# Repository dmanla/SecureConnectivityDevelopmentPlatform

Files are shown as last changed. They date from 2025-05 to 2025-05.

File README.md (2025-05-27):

# Arduino-Mega Compatible Secure Connectivity Development Platform

**WARNING**: This project is under development and has not yet been validated.

This is an open hardware platform designed for the development of secure wired-network applications. It is fully compatible with all Arduino Mega-compatible hardware and software.

This project was inspired by (but not a copy of) the Freetronics EtherMega: https://github.com/freetronics/EtherMega
This project was created as an alternative to the platform offered by Freetronics.

Features:
- CH340 USB->Serial Converter (Functionally similar to FT232, Driver should be installed automatically)
- Jumper Configurable IO: Certain pins (D3, D6, D8, D9, D13) can be connected to the headers or to integrated peripheral pins.
- 5V 2A USB-C Input
- 6V - 32V VIN Input 
- MicroSD Card Slot
- 10/100 Ethernet provided over SPI using the W6100. Supports Auto-Negotiations, IPv4, IPv6, and Auto-MIDX.
- SE050 EdgeLock Plug and Trust Secure Element to provide security features for connected applications, accessible using I2C
- ISM330DHCX Inertial Measurement Unit, accessible using I2C
- MCP7940N Real Time Clock, accessible using I2C
- Level Shifted I2C: Provides connection points for 3V3 I2C Devices (Extra Header), and 5V I2C Devices (Standard Mega Headers)

## Top Render
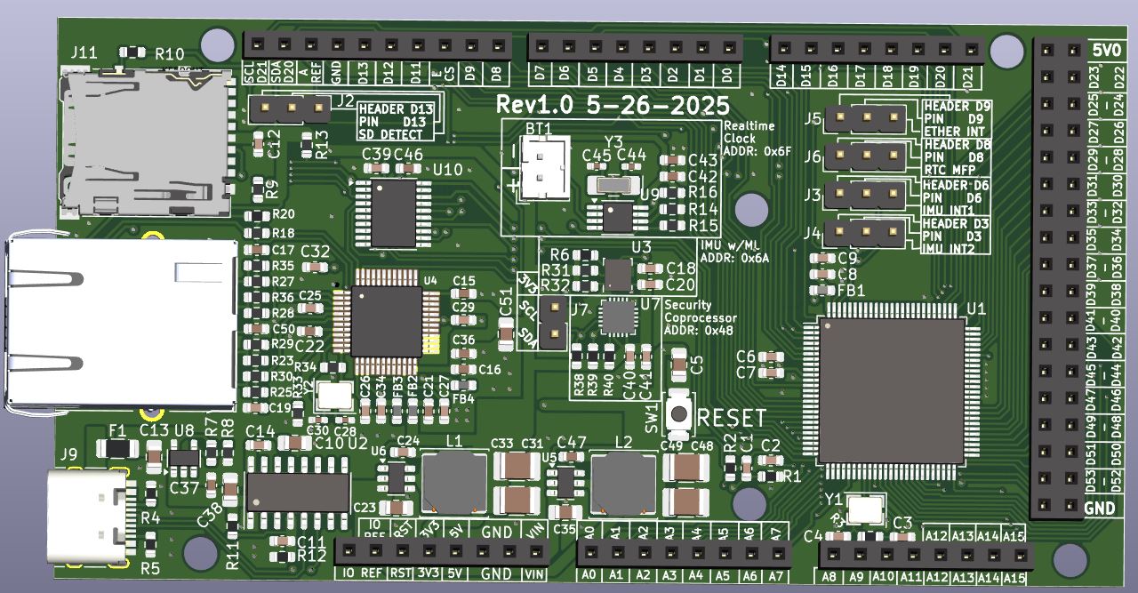
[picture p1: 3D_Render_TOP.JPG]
Render of Top of PCB


## Bottom Render
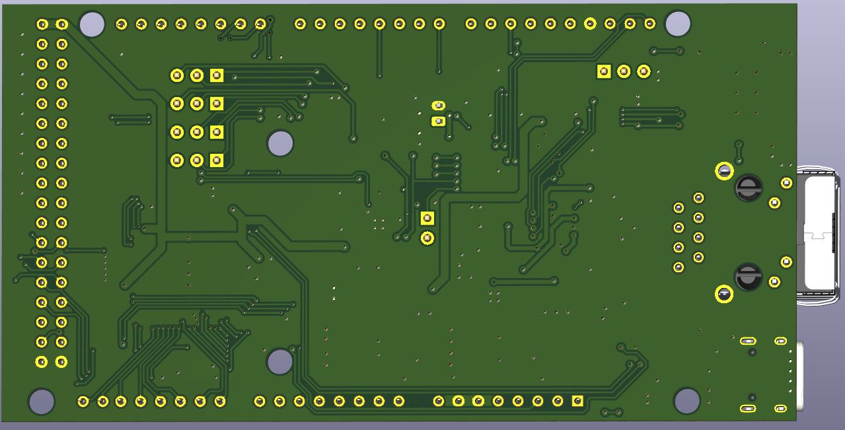
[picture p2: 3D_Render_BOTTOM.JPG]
Render of Bottom of PCB


## Side Render
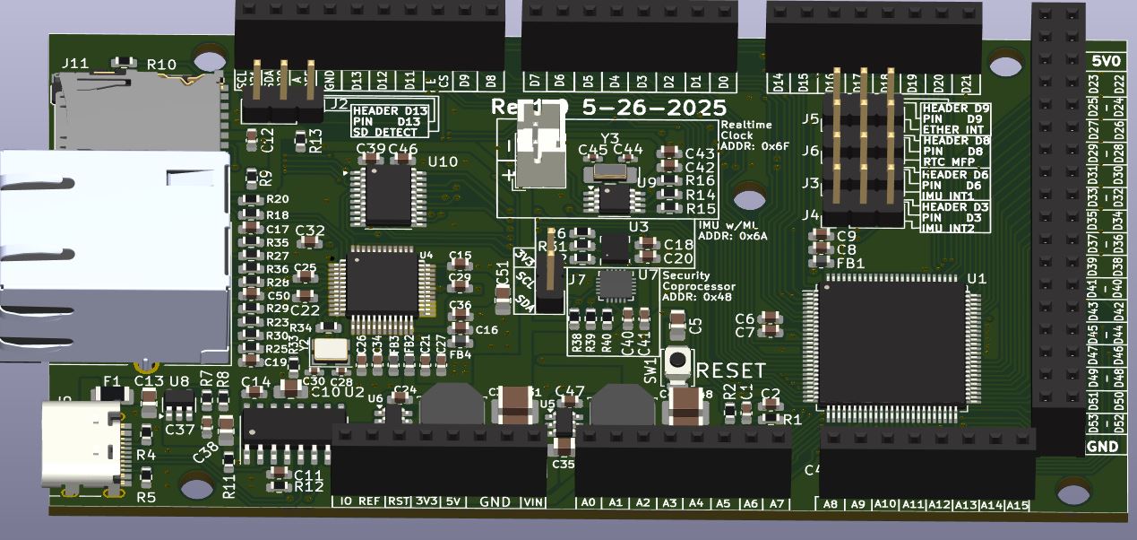
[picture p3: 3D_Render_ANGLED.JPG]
Render of Side of PCB


## Relevant Datasheets

- [CH340N](https://datasheet.lcsc.com/szlcsc/Jiangsu-Qin-Heng-CH340C_C84681.pdf): USB->Serial Bridge
- [AP22805AW5](https://www.diodes.com/assets/Datasheets/AP22804_14.pdf): USB Protection
- [AP63205](https://www.diodes.com/assets/Datasheets/AP63200-AP63201-AP63203-AP63205.pdf): DC-DC Switching Converters
- [W6100](https://docs.wiznet.io/img/products/w6100/w6100_ds_v105e.pdf): SPI->Ethernet Bridge
- [ISM330DHCX](https://www.st.com/resource/en/datasheet/ism330dhcx.pdf): "AI Enabled" Inertial Measurement Unit
- [SE050C2HQ1](https://www.nxp.com/docs/en/data-sheet/SE050-DATASHEET.pdf): Security Coprocessor
- [MCP7940N](http://ww1.microchip.com/downloads/en/DeviceDoc/20005010F.pdf): Real-Time Clock **with** Battery Backup
- [Atmega2560](http://ww1.microchip.com/downloads/en/DeviceDoc/Atmel-2549-8-bit-AVR-Microcontroller-ATmega640-1280-1281-2560-2561_datasheet.pdf): Main Microcontroller

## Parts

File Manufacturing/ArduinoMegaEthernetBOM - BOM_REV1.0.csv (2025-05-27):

 |  |  | Arduino Mega with Ethernet
Item # | Designator | *Qty | Manufacturer | Mfg Part # | Description / Value | Package/Footprint | Type | Your Instructions / Notes | Unit Cost | Per Board Cost
1 | BT1 | 1 | JST Sales America Inc. | B2B-PH-K-S | CONN HEADER VERT 2POS 2MM | JST_PH_B2B-PH-K_1x02_P2.00mm_Vertical | THT | N/A | $0.120 | $0.120
2 | C1, C7-C9, C11, C12, C14-C19, C21, C22, C24-C27, C29, C32, C37, C40, C42, C47, C50 | 25 | CCTC | TCC0603X7R104K250CT | CAP CER 0.1UF 25V X7R 0603 | C_0603_1608Metric | SMD | N/A | $0.002 | $0.053
3 | C2, C3, C4 | 3 | Walsin Technology | 0603N220J500CT | CAP CER 22PF 50V C0G/NP0 0603 | C_0603_1608Metric | SMD | N/A | $0.100 | $0.300
4 | C5, C13, C23, C35, C36, C38 | 6 | CCTC | TCC0805X5R106K500FT | 50V 10uF X5R ±10% 0805 | C_0805_2012Metric | SMD | N/A | $0.042 | $0.251
5 | C6, C20, C34, C39, C41, C43, C46 | 7 | CCTC | TCC0603X7R105K160CT | 16V 1uF X7R ±10% 0603 | C_0603_1608Metric | SMD | N/A | $0.004 | $0.027
6 | C10, C21 | 2 | Murata Electronics | GRM21BR71C475KE51K | CAP CER 4.7UF 16V X7R 0805 | C_0805_2012Metric | SMD | N/A | $0.120 | $0.240
7 | C28, C30 | 2 | Murata Electronics | GJM1555C1H180GB01D | CAP CER 18PF 50V C0G/NP0 0402 | C_0603_1608Metric | SMD | N/A | $0.140 | $0.280
8 | C31, C33, C48, C49 | 4 | Samsung Electro-Mechanics | CL31B226KPHNNNE | CAP CER 22UF 10V X7R 1206 | C_0805_2012Metric_Pad1.18x1.45mm | SMD | N/A | $0.066 | $0.262
9 | C44, C45 | 2 | YAGEO | CC0402JRNPO9BN120 | CAP CER 12PF 50V C0G/NPO 0402 | C_0402_1005Metric | SMD | N/A | $0.020 | $0.040
10 | F1 | 1 | YAGEO | SMD1206B200TF | PTC RESET FUSE 6V 2A 1206 | Fuse_1206_3216Metric | SMD | N/A | $0.130 | $0.130
11 | FB1-FB4 | 4 | Murata Electronics | BLM18KG121TN1D | FERRITE BEAD 120 OHM 0603 1LN | L_0603_1608Metric | SMD | N/A | $0.100 | $0.400
12 | J1 | 1 | WIZNET | RB1-125BAG1A | RJ45Receptacle 1 Shielded Right-Angle cat | RJ45_Amphenol_RJMG1BD3B8K1ANR | THT | N/A | $3.400 | $3.400
13 | J2, J3, J4, J5, J6 | 5 | XFCN | PZ254V-11-03P | CONN HEADER VERT 3POS 2.54MM | PinHeader_1x03_P2.54mm_Vertical | SMD | N/A | $0.015 | $0.075
14 | J7 | 1 | XFCN | PZ254V-11-02P | CONN HEADER VERT 2POS 2.54MM | PinHeader_1x02_P2.54mm_Vertical | SMD | N/A | $0.013 | $0.013
15 | J9 | 1 | Same Sky | UJ20-C-H-G-SMT-P16-TR | USB JACK, TYPE C, 2.0, HORIZONTAL | USB_C_Receptacle_HRO_TYPE-C-31-M-12 | SMD | N/A | $0.570 | $0.570
16 | J11 | 1 | Hirose Electric Co Ltd | DM3AT-SF-PEJM5 | CONN MICRO SD CARD R/A SMD | microSD_HC_Hirose_DM3AT-SF-PEJM5 | SMD | N/A | $2.660 | $2.660
17 | L1, L2 | 2 | Taiyo Yuden | NRS6028T4R7MMGKV | FIXED IND 4.7UH 3A 40.3 MOHM SMD | 0.236" L x 0.236" W (6.00mm x 6.00mm) | SMD | N/A | $0.290 | $0.580
18 | R1, R2, R6, R9, R10, R13 | 6 | FOJAN | FRC0603F1002TS | RES 10K OHM 1% 1/10W 0603 | R_0603_1608Metric | SMD | N/A | $0.001 | $0.005
19 | R3, R34 | 2 | YAGEO | AC0603FR-101ML | RES 1M OHM 1% 1/10W 0603 | R_0603_1608Metric | SMD | N/A | $0.100 | $0.200
20 | R4, R5, R7 | 3 | YAGEO | RC0603FR-075K1L | RES 5.1K OHM 1% 1/10W 0603 | R_0603_1608Metric | SMD | N/A | $0.009 | $0.027
21 | R8 | 1 |  |  | DNP | R_0603_1608Metric | SMD | DO NOT PLACE |  | $0.000
22 | R11 | 1 | YAGEO | RC0603FR-0722K1L | RES 22.1K OHM 1% 1/10W 0603 | R_0603_1608Metric | SMD | N/A | $0.100 | $0.100
23 | R12 | 1 | YAGEO | RC0603FR-0747K5L | RES 47.5K OHM 1% 1/10W 0603 | R_0603_1608Metric | SMD | N/A | $0.100 | $0.100
24 | R14-R16, R31, R32, R38-R40 | 8 | FOJAN | FRC0603F4701TS | RES 4.7K OHM 1% 1/10W 0603 | R_0603_1608Metric | SMD | N/A | $0.001 | $0.008
25 | R18, R20 | 2 | YAGEO | RC0603FR-07470RL | RES 470 OHM 1% 1/10W 0603 | R_0603_1608Metric | SMD | N/A | $0.001 | $0.003
26 | R23, R25, R35, R36 | 4 | YAGEO | RC0603FR-0749R9L | RES 49.9R OHM 1% 1/10W 0603 | R_0603_1608Metric | SMD | N/A | $0.009 | $0.036
27 | R27-R30 | 4 | Vishay Intertech | CRCW06033R30FKEAHP | ±1% 3.3Ω 333mW 0603 | R_0603_1608Metric | SMD | N/A | $0.091 | $0.364
28 | R33 | 1 | KOA Speer Electronics, Inc. | RN73R1JTTD1232F100 | RES 12.3K OHM 1% 1/10W 0603 | R_0603_1608Metric | SMD | N/A | $0.100 | $0.100
29 | SW1 | 1 | Alps Alpine | SKRKAHE020 | SWITCH TACTILE SPST-NO 0.05A 12V | SW_SPST_PTS645 | SMD | N/A | $0.126 | $0.126
30 | U1 | 1 | Microchip Technology | ATMEGA2560-16AU | IC MCU 8BIT 256KB FLASH 100TQFP | TQFP-100_14x14mm_P0.5mm | SMD | N/A | $12.710 | $12.710
31 | U2 | 1 | WCH(Jiangsu Qin Heng) | CH340C | 2Mbps transceiver USB 2.0 SOP-16 USB | SOIC-16_3.9x9.9mm_P1.27mm | SMD | N/A | $0.524 | $0.524
32 | U3 | 1 | STMicroelectronics | ISM330DHCXTR | INEMO INERTIAL MODULE: ALWAYS-ON | LGA-14_3x2.5mm_P0.5mm_LayoutBorder3x4y | SMD | N/A | $6.564 | $6.564
33 | U4 | 1 | WIZnet | W6100-LQFP | IC CTLR 3-1 ETH TCP/IP 48LQFP | LQFP-48_7x7mm_P0.5mm | SMD | N/A | $2.190 | $2.190
34 | U5 | 1 | Diodes Incorporated | AP63205QWU-7 | IC REG BUCK 5V 2A TSOT23-6 | TSOT-23-6 | SMD | N/A | $0.960 | $0.960
35 | U6 | 1 | Diodes Incorporated | AP63203WU-7 | IC REG BUCK 3.3V 2A TSOT23-6 | TSOT-23-6 | SMD | N/A | $0.710 | $0.710
36 | U7 | 1 | NXP USA Inc. | SE050C2HQ1/Z01SDZ | IC IOT SECURE ELEMENT 20-HX2QFN | QFN-20-1EP_3x3mm_P0.4mm_EP1.65x1.65mm | SMD | N/A | $5.190 | $5.190
37 | U8 | 1 | Diodes Incorporated | AP22804AW5-7 | IC PWR SWITCH P-CHAN 1:1 SOT25 | SOT-23-5 | SMD | N/A | $0.350 | $0.350
38 | U9 | 1 | Microchip Technology | MCP7940N-E/MS | IC RTC CLK/CALENDAR I2C 8MSOP | MSOP-8_3x3mm_P0.65mm | SMD | N/A | $0.970 | $0.970
39 | U10 | 1 | Texas Instruments | TXS0108EPWR | IC TRANSLATOR BIDIR 20TSSOP | TSSOP-20_4.4x6.5mm_P0.65mm | SMD | N/A | $0.223 | $0.223
40 | Y1 | 1 | YXC Crystal Oscillators | X322516MOB4SI | CRYSTAL 16.0000MHZ 12PF SMD | Crystal_SMD_3225-4Pin_3.2x2.5mm | SMD | N/A | $0.061 | $0.061
41 | Y2 | 1 | Raltron Electronics | RH100-25.000-10-F-2030-EXT-TR | CRYSTAL 25.0000MHZ 10PF SMD | Crystal_SMD_3225-4Pin_3.2x2.5mm | SMD | N/A | $0.230 | $0.230
42 | Y3 | 1 | YIC | 32.768K7PI/3215E | CRYSTAL 32.7680KHZ 7PF SMD | 0.126" L x 0.059" W (3.20mm x 1.50mm) | SMD | N/A | $0.280 | $0.280
 |  |  |  |  |  |  |  | Total Cost Per Board: |  | $41.43
 |  |  |  |  |  |  |  | Manufacturing Cost: |  | $1.00
 |  |  |  |  |  |  |  |  | Total: | $42.43

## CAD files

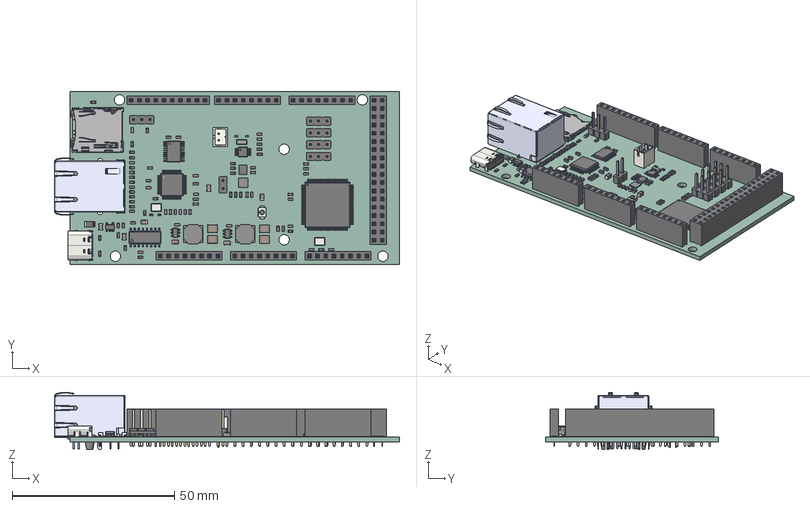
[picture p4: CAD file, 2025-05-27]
Manufacturing/ArduinoMega_Ethernet.step
106.5 x 53.3 x 17.7 mm
SE050C2HQ1-Z01SDZ--3DModel-STEP-56544
R_0603_1608Metric x 33
TSSOP-20_4.4x6.5mm_P0.65mm
PinHeader_1x03_P2.54mm_Vertical x 5
C_0603_1608Metric x 36
C_1210_3225Metric x 4
JST_PH_B2B-PH-K_1x02_P2.00mm_Vertical
SOT-23-5
L_0603_1608Metric x 4
LQFP-48_7x7mm_P0.5mm
LGA-14_3x2.5mm_P0.5mm_LayoutBorder3x4y
C_0805_2012Metric x 7
C_0402_1005Metric x 4
Crystal_SMD_3225-4Pin_3.2x2.5mm x 2
SW_SPST_B3U-1000P-B
TSOT-23-6 x 2
NRS6028T4R7MMGKV x 2
RB1-125BAG1A
SOIC-16_3.9x9.9mm_P1.27mm
Crystal_SMD_3215-2Pin_3.2x1.5mm
MSOP-8_3x3mm_P0.65mm
PinSocket_1x08_P2.54mm_Vertical x 5
PinSocket_1x10_P2.54mm_Vertical
PinSocket_2x18_P2.54mm_Vertical
microSD_HC_Hirose_DM3AT-SF-PEJM5
TQFP-100_14x14mm_P0.5mm
USB_C_Receptacle_GCT_USB4105-xx-A_16P_TopMnt_Horizontal
Fuse_1206_3216Metric
PinHeader_1x02_P2.54mm_Vertical
ArduinoMega_Ethernet_PCB

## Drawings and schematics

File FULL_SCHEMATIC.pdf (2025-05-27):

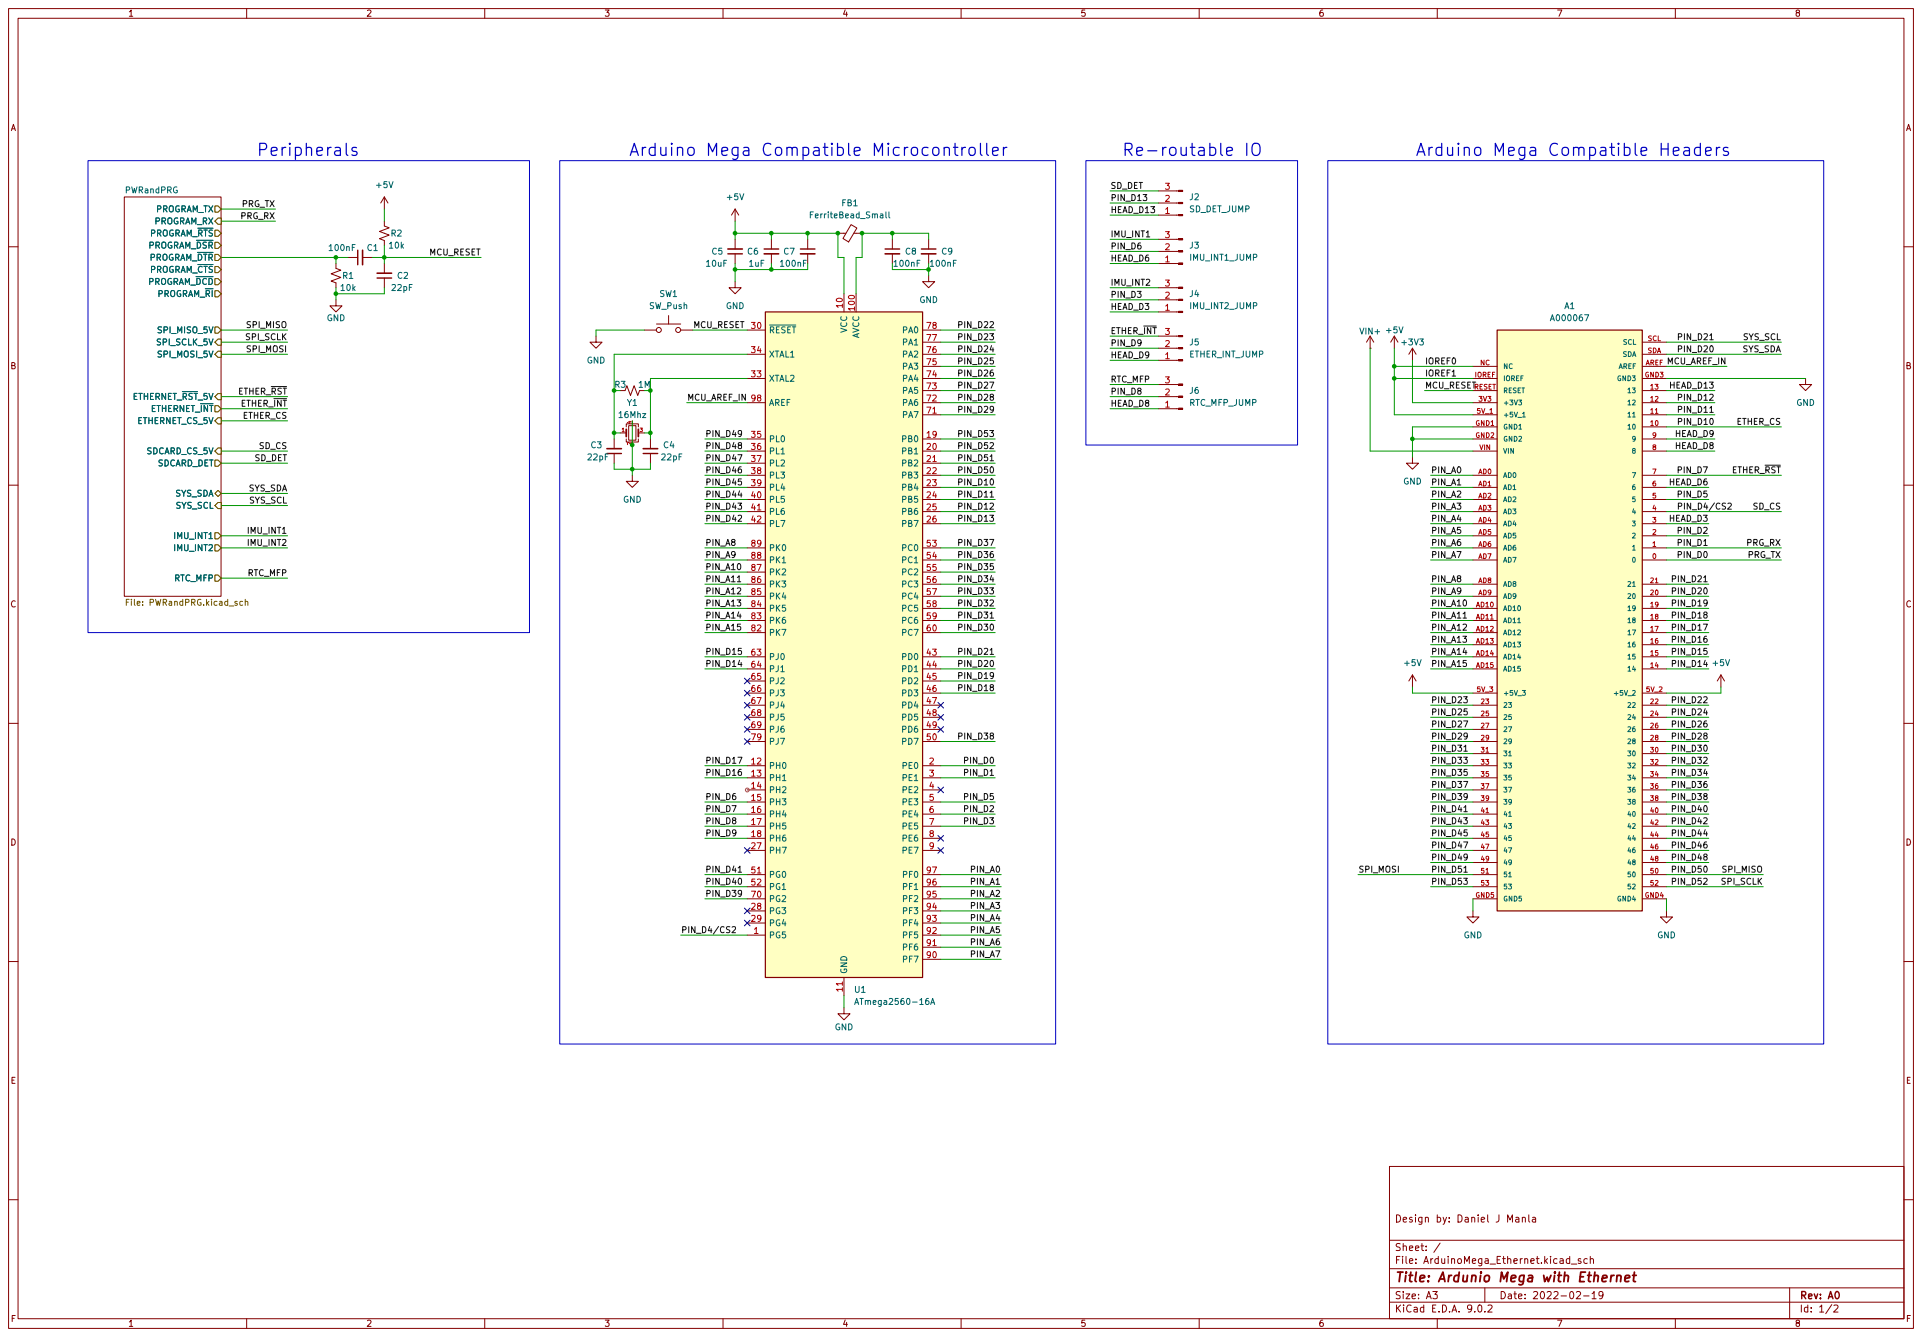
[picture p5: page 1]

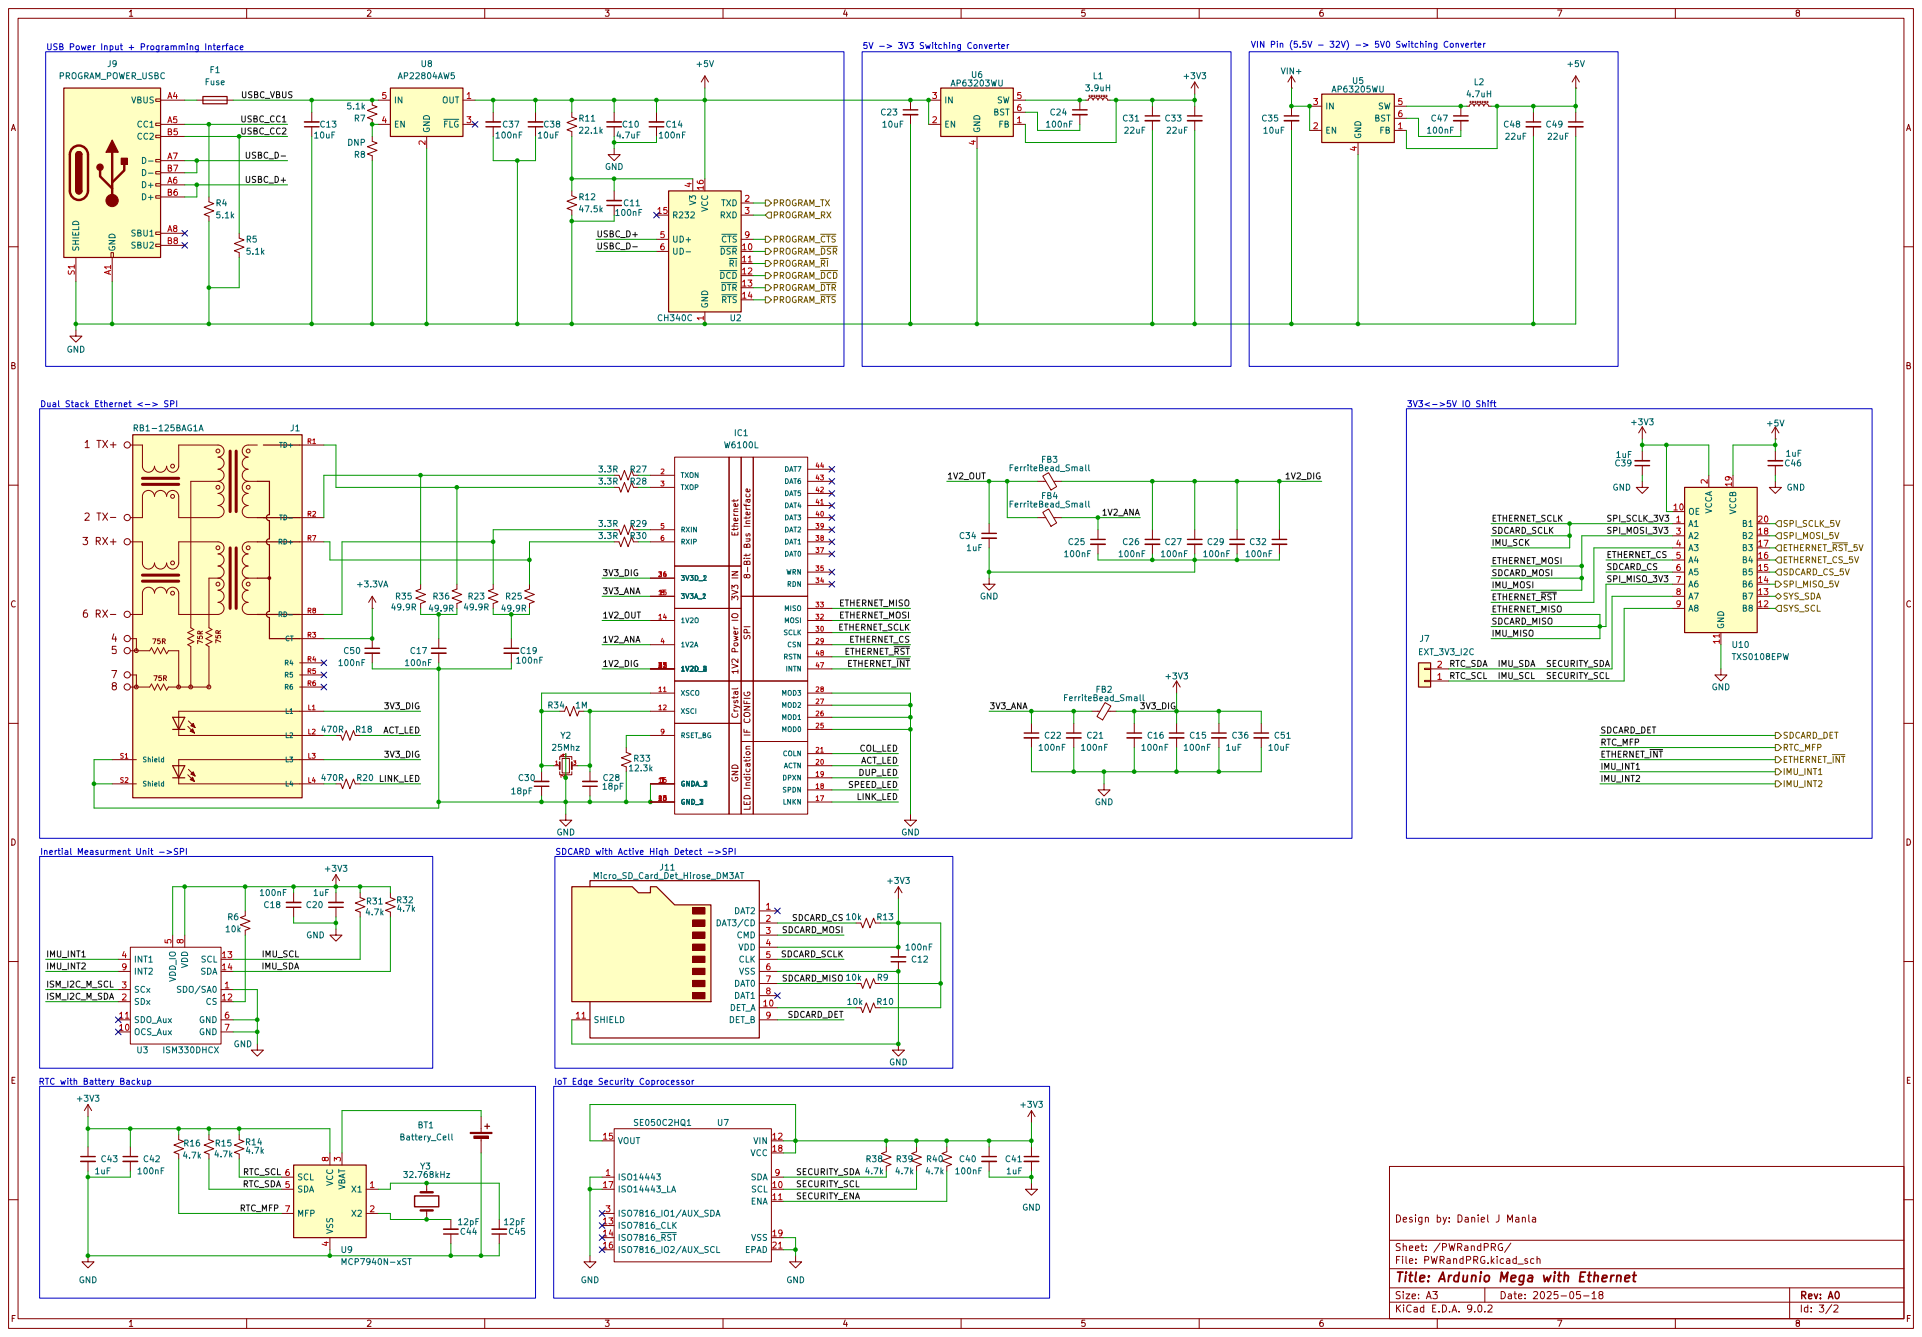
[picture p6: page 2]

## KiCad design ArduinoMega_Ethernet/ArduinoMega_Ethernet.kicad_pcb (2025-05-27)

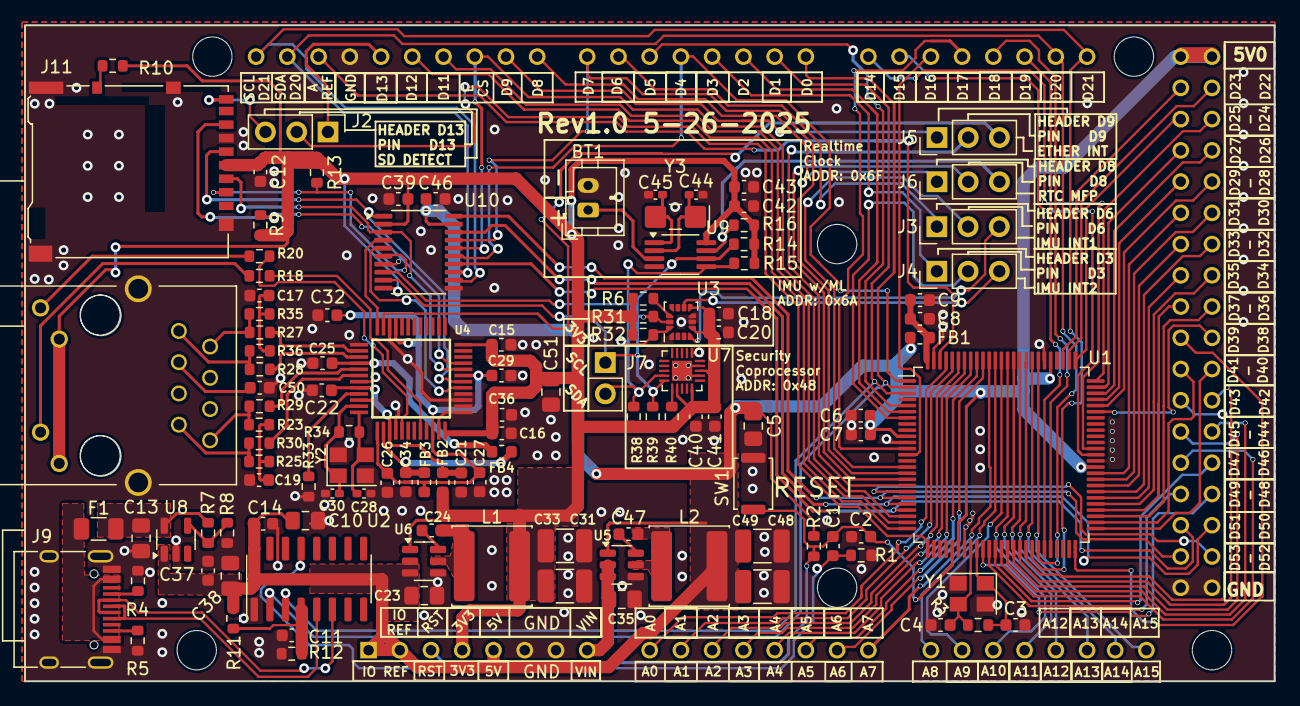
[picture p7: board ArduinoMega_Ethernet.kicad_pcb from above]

Board: 2 copper layers, 101.6 x 53.3 mm, 116 parts (0 on the bottom side), 138 nets.

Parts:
A1: A000067; ARDUINO_A000067
BT1: Battery_Cell; JST_PH_B2B-PH-K_1x02_P2.00mm_Vertical
C1, C7, C8, C9, C11, C12, C14, C15, C16, C17, C18, C19, C21, C22, C24, C25, C26, C27, C29, C32, C37, C40, C42, C47, C50: 100nF; C_0603_1608Metric
C2, C3, C4: 22pF; C_0603_1608Metric
C5, C13, C23, C35, C38, C51: 10uF; C_0805_2012Metric_Pad1.18x1.45mm_HandSolder
C6, C20, C34, C36, C39, C41, C43, C46: 1uF; C_0603_1608Metric
C10: 4.7uF; C_0805_2012Metric_Pad1.18x1.45mm_HandSolder
C28, C30: 18pF; C_0402_1005Metric_Pad0.74x0.62mm_HandSolder
C31, C33, C48, C49: 22uF; C_1210_3225Metric_Pad1.33x2.70mm_HandSolder
C44, C45: 12pF; C_0402_1005Metric_Pad0.74x0.62mm_HandSolder
F1: Fuse; Fuse_1206_3216Metric
FB1, FB2, FB3, FB4: FerriteBead_Small; L_0603_1608Metric
J1: RB1-125BAG1A; WIZNET_RB1-125BAG1A
J2: SD_DET_JUMP; PinHeader_1x03_P2.54mm_Vertical
J3: IMU_INT1_JUMP; PinHeader_1x03_P2.54mm_Vertical
J4: IMU_INT2_JUMP; PinHeader_1x03_P2.54mm_Vertical
J5: ETHER_INT_JUMP; PinHeader_1x03_P2.54mm_Vertical
J6: RTC_MFP_JUMP; PinHeader_1x03_P2.54mm_Vertical
J7: EXT_3V3_I2C; PinHeader_1x02_P2.54mm_Vertical
J9: PROGRAM_POWER_USBC; USB_C_Receptacle_HRO_TYPE-C-31-M-12
J11: Micro_SD_Card_Det_Hirose_DM3AT; microSD_HC_Hirose_DM3AT-SF-PEJM5
L1: 3.9uH; L_APV_ANR6028
L2: 4.7uH; L_APV_ANR6028
R1, R2, R6, R9, R10, R13: 10k; R_0603_1608Metric
R3, R34: 1M; R_0603_1608Metric
R4, R5, R7: 5.1k; R_0603_1608Metric
R8: DNP; R_0603_1608Metric
R11: 22.1k; R_0603_1608Metric
R12: 47.5k; R_0603_1608Metric
R14, R15, R16, R31, R32, R38, R39, R40: 4.7k; R_0603_1608Metric
R18, R20: 470R; R_0603_1608Metric
R23, R25, R35, R36: 49.9R; R_0603_1608Metric
R27, R28, R29, R30: 3.3R; R_0603_1608Metric
R33: 12.3k; R_0603_1608Metric
SW1: SW_Push; SW_Push_SPST_NO_Alps_SKRK
U1: ATmega2560-16A; TQFP-100_14x14mm_P0.5mm
U2: CH340C; SOIC-16_3.9x9.9mm_P1.27mm
U3: ISM330DHCX; LGA-14_3x2.5mm_P0.5mm_LayoutBorder3x4y
U4: W6100L; QFP50P900X900X160-48N
U5: AP63205WU; TSOT-23-6
U6: AP63203WU; TSOT-23-6
U7: SE050C2HQ1; QFN-20-1EP_3x3mm_P0.4mm_EP1.65x1.65mm
U8: AP22804AW5; SOT-23-5
U9: MCP7940N-xST; MSOP-8_3x3mm_P0.65mm
U10: TXS0108EPW; TSSOP-20_4.4x6.5mm_P0.65mm
Y1: 16Mhz; Crystal_SMD_3225-4Pin_3.2x2.5mm
Y2: 25Mhz; Crystal_SMD_3225-4Pin_3.2x2.5mm
Y3: 32.768kHz; Crystal_SMD_EuroQuartz_EQ161-2Pin_3.2x1.5mm_HandSoldering

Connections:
+3.3VA: C50.1, J1.R3 (CT)
+3V3: A1.3V3 (+3V3), C12.2, C15.1, C16.1, C18.2, C20.2, C31.1, C33.1, C36.1, C39.2, C40.1, C41.1, C42.1, C43.1, C51.1, FB2.2, J1.L1, J1.L3, J11.4 (VDD), L1.2, R6.1, R9.1, R10.1, R13.1, R14.1, R15.1, R16.1, R31.1, R32.1, R38.1, R39.1, R40.1, U3.5 (VDD_IO), U3.8 (VDD), U4.24 (3V3D_1), U4.36 (3V3D_2), U6.1 (FB), U7.12 (VIN), U7.15 (VOUT), U7.18 (VCC), U9.8 (VCC), U10.2 (VCCA), U10.10 (OE)
+5V: A1.5V_1 (+5V_1), A1.5V_2 (+5V_2), A1.5V_3 (+5V_3), A1.IOREF, A1.NC, C5.2, C6.1, C7.1, C10.2, C14.2, C23.1, C37.2, C38.2, C46.2, C48.1, C49.1, FB1.1, L2.2, R2.1, R11.2, U1.10 (VCC), U1.31 (VCC), U1.61 (VCC), U1.80 (VCC), U2.16 (VCC), U5.1 (FB), U6.2 (EN), U6.3 (IN), U8.1 (OUT), U10.19 (VCCB)
/ETHER_CS: A1.10, U1.23 (PB4), U10.16 (B4)
/ETHER_~INT: J5.3, U4.47 (INTN)
/ETHER_~RST: A1.7, U1.16 (PH4), U10.17 (B3)
/HEAD_D3: A1.3, J4.1
/HEAD_D6: A1.6, J3.1
/HEAD_D8: A1.8, J6.1
/HEAD_D9: A1.9, J5.1
/HEAD_D13: A1.13, J2.1
/IMU_INT1: J3.3, U3.4 (INT1)
/IMU_INT2: J4.3, U3.9 (INT2)
/MCU_AREF_IN: A1.AREF, U1.98 (AREF)
/MCU_RESET: A1.RESET, C1.2, C2.2, R2.2, SW1.2, U1.30 (~RESET)
/PIN_A0: A1.AD0, U1.97 (PF0)
/PIN_A1: A1.AD1, U1.96 (PF1)
/PIN_A2: A1.AD2, U1.95 (PF2)
/PIN_A3: A1.AD3, U1.94 (PF3)
/PIN_A4: A1.AD4, U1.93 (PF4)
/PIN_A5: A1.AD5, U1.92 (PF5)
/PIN_A6: A1.AD6, U1.91 (PF6)
/PIN_A7: A1.AD7, U1.90 (PF7)
/PIN_A8: A1.AD8, U1.89 (PK0)
/PIN_A9: A1.AD9, U1.88 (PK1)
/PIN_A10: A1.AD10, U1.87 (PK2)
/PIN_A11: A1.AD11, U1.86 (PK3)
/PIN_A12: A1.AD12, U1.85 (PK4)
/PIN_A13: A1.AD13, U1.84 (PK5)
/PIN_A14: A1.AD14, U1.83 (PK6)
/PIN_A15: A1.AD15, U1.82 (PK7)
/PIN_D0: A1.0, U1.2 (PE0), U2.2 (TXD)
/PIN_D1: A1.1, U1.3 (PE1), U2.3 (RXD)
/PIN_D2: A1.2, U1.6 (PE4)
/PIN_D3: J4.2, U1.7 (PE5)
/PIN_D4/CS2: A1.4, U1.1 (PG5), U10.15 (B5)
/PIN_D5: A1.5, U1.5 (PE3)
/PIN_D6: J3.2, U1.15 (PH3)
/PIN_D8: J6.2, U1.17 (PH5)
/PIN_D9: J5.2, U1.18 (PH6)
/PIN_D11: A1.11, U1.24 (PB5)
/PIN_D12: A1.12, U1.25 (PB6)
/PIN_D13: J2.2, U1.26 (PB7)
/PIN_D14: A1.14, U1.64 (PJ1)
/PIN_D15: A1.15, U1.63 (PJ0)
/PIN_D16: A1.16, U1.13 (PH1)
/PIN_D17: A1.17, U1.12 (PH0)
/PIN_D18: A1.18, U1.46 (PD3)
/PIN_D19: A1.19, U1.45 (PD2)
/PIN_D20: A1.20, A1.SDA, U1.44 (PD1), U10.13 (B7)
/PIN_D21: A1.21, A1.SCL, U1.43 (PD0), U10.12 (B8)
/PIN_D22: A1.22, U1.78 (PA0)
/PIN_D23: A1.23, U1.77 (PA1)
/PIN_D24: A1.24, U1.76 (PA2)
/PIN_D25: A1.25, U1.75 (PA3)
/PIN_D26: A1.26, U1.74 (PA4)
/PIN_D27: A1.27, U1.73 (PA5)
/PIN_D28: A1.28, U1.72 (PA6)
/PIN_D29: A1.29, U1.71 (PA7)
/PIN_D30: A1.30, U1.60 (PC7)
/PIN_D31: A1.31, U1.59 (PC6)
/PIN_D32: A1.32, U1.58 (PC5)
/PIN_D33: A1.33, U1.57 (PC4)
/PIN_D34: A1.34, U1.56 (PC3)
/PIN_D35: A1.35, U1.55 (PC2)
/PIN_D36: A1.36, U1.54 (PC1)
/PIN_D37: A1.37, U1.53 (PC0)
/PIN_D38: A1.38, U1.50 (PD7)
/PIN_D39: A1.39, U1.70 (PG2)
/PIN_D40: A1.40, U1.52 (PG1)
/PIN_D41: A1.41, U1.51 (PG0)
/PIN_D42: A1.42, U1.42 (PL7)
/PIN_D43: A1.43, U1.41 (PL6)
/PIN_D44: A1.44, U1.40 (PL5)
/PIN_D45: A1.45, U1.39 (PL4)
/PIN_D46: A1.46, U1.38 (PL3)
/PIN_D47: A1.47, U1.37 (PL2)
/PIN_D48: A1.48, U1.36 (PL1)
/PIN_D49: A1.49, U1.35 (PL0)
/PIN_D50: A1.50, U1.22 (PB3), U10.14 (B6)
/PIN_D51: A1.51, U1.21 (PB2), U10.18 (B2)
/PIN_D52: A1.52, U1.20 (PB1), U10.20 (B1)
/PIN_D53: A1.53, U1.19 (PB0)
/PWRandPRG/1V2_ANA: C25.1, FB4.1, U4.4 (1V2A)
/PWRandPRG/1V2_DIG: C26.1, C27.1, C29.1, C32.1, FB3.1, U4.13 (1V2D_1), U4.22 (1V2D_2), U4.31 (1V2D_3), U4.45 (1V2D_4)
/PWRandPRG/1V2_OUT: C34.1, FB3.2, FB4.2, U4.14 (1V2O)
/PWRandPRG/3V3_ANA: C21.1, C22.1, FB2.1, U4.8 (3V3A_1), U4.15 (3V3A_2)
/PWRandPRG/ACT_LED: R18.1, U4.20 (ACTN)
/PWRandPRG/ETHERNET_CS: U4.29 (CSN), U10.5 (A4)
/PWRandPRG/ETHERNET_MISO: J11.7 (DAT0), R9.2, U4.33 (MISO), U10.7 (A6)
/PWRandPRG/ETHERNET_MOSI: J11.3 (CMD), U4.32 (MOSI), U10.3 (A2)
/PWRandPRG/ETHERNET_SCLK: J11.5 (CLK), U4.30 (SCLK), U10.1 (A1)
/PWRandPRG/ETHERNET_~RST: U4.48 (RSTN), U10.4 (A3)
/PWRandPRG/IMU_SCL: J7.1, R14.2, R31.2, R39.2, U3.13 (SCL), U7.10 (SCL), U9.6 (SCL), U10.9 (A8)
/PWRandPRG/IMU_SDA: J7.2, R15.2, R32.2, R38.2, U3.14 (SDA), U7.9 (SDA), U9.5 (SDA), U10.8 (A7)
/PWRandPRG/LINK_LED: R20.1, U4.17 (LNKN)
/PWRandPRG/PROGRAM_~DTR: C1.1, R1.1, U2.13 (~DTR)
/PWRandPRG/SDCARD_CS: J11.2 (DAT3/CD), R13.2, U10.6 (A5)
/PWRandPRG/SECURITY_ENA: R40.2, U7.11 (ENA)
/PWRandPRG/USBC_CC1: J9.A5 (CC1), R4.2
/PWRandPRG/USBC_CC2: J9.B5 (CC2), R5.2
/PWRandPRG/USBC_D+: J9.A6 (D+), J9.B6 (D+), U2.5 (UD+)
/PWRandPRG/USBC_D-: J9.A7 (D-), J9.B7 (D-), U2.6 (UD-)
/PWRandPRG/USBC_VBUS: C13.2, F1.1, R7.1, U8.5 (IN)
/RTC_MFP: J6.3, R16.2, U9.7 (MFP)
/SD_DET: J2.3, J11.9 (DET_B)
GND: A1.GND1, A1.GND2, A1.GND3, A1.GND4, A1.GND5, BT1.2 (-), C2.1, C3.1, C4.1, C5.1, C6.2, C7.2, C8.2, C9.2, C10.1, C11.1, C12.1, C13.1, C14.1, C15.2, C16.2, C17.2, C18.1, C19.2, C20.1, C21.2, C22.2, C23.2, C25.2, C26.2, C27.2, C28.1, C29.2, C30.1, C31.2, C32.2, C33.2, C34.2, C35.2, C36.2, C37.1, C38.1, C39.1, C40.2, C41.2, C42.2, C43.2, C44.1, C45.1, C46.1, C48.2, C49.2, C50.2, C51.2, J1.S1 (Shield), J1.S2 (Shield), J9.A1 (GND), J9.A12 (GND), J9.B1 (GND), J9.B12 (GND), J9.S1 (SHIELD), J11.6 (VSS), J11.11 (SHIELD), R1.2, R4.1, R5.1, R8.2, R12.1, R33.2, SW1.1, U1.11 (GND), U1.32 (GND), U1.62 (GND), U1.81 (GND), U1.99 (GND), U2.1 (GND), U3.1 (SDO/SA0), U3.6 (GND), U3.7 (GND), U4.1 (GNDA_1), U4.7 (GNDA_2), U4.10 (GND_1), U4.16 (GNDA_3), U4.23 (GND_2), U4.25 (MOD0), U4.26 (MOD1), U4.27 (MOD2), U4.28 (MOD3), U4.46 (GND_3), U5.4 (GND), U6.4 (GND), U7.1 (ISO14443), U7.17 (ISO14443_LA), U7.19 (VSS), U7.21 (EPAD), U8.2 (GND), U9.4 (VSS), U10.11 (GND), Y1.2, Y1.4, Y2.2, Y2.4
unnamed: BT1.1 (+), U9.3 (VBAT)
unnamed: C17.1, R35.2, R36.2
unnamed: C19.1, R23.2, R25.2
unnamed: F1.2, J9.A4 (VBUS), J9.A9 (VBUS), J9.B4 (VBUS), J9.B9 (VBUS)
unnamed: R33.1, U4.9 (RSET_BG)
unnamed: R29.1, U4.5 (RXIN)
unnamed: R30.1, U4.6 (RXIP)
unnamed: R27.1, U4.2 (TXON)
unnamed: R28.1, U4.3 (TXOP)
unnamed: C28.2, R34.2, U4.12 (XSCI), Y2.3
unnamed: C30.2, R34.1, U4.11 (XSCO), Y2.1
unnamed: J1.L2, R18.2
unnamed: J1.L4, R20.2
unnamed: J1.R7 (RD+), R25.1, R30.2
unnamed: J1.R8 (RD-), R23.1, R29.2
unnamed: J1.R1 (TD+), R28.2, R36.1
unnamed: J1.R2 (TD-), R27.2, R35.1
unnamed: J11.10 (DET_A), R10.2
unnamed: C8.1, C9.1, FB1.2, U1.100 (AVCC)
unnamed: C3.2, R3.1, U1.34 (XTAL1), Y1.1
unnamed: C4.2, R3.2, U1.33 (XTAL2), Y1.3
unnamed: C11.2, R11.1, R12.2, U2.4 (V3)
unnamed: R6.2, U3.12 (CS)
unnamed: C47.2, U5.6 (BST)
unnamed: C47.1, L2.1, U5.5 (SW)
unnamed: C24.2, U6.6 (BST)
unnamed: C24.1, L1.1, U6.5 (SW)
unnamed: R7.2, R8.1, U8.4 (EN)
unnamed: C45.2, U9.1 (X1), Y3.2
unnamed: C44.2, U9.2 (X2), Y3.1
VIN+: A1.VIN, C35.1, U5.2 (EN), U5.3 (IN)

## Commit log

2025-05-26 w6100 manufacturing and project files
    [ArduinoMega_Ethernet-B_Cu.gbr, ArduinoMega_Ethernet-B_Mask.gbr, ArduinoMega_Ethernet-B_Paste.gbr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]
2025-05-27 bom and component sizing
    [ArduinoMegaEthernetBOM - BOM_REV1.0.csv, ArduinoMegaEthernetBOM.ods, ArduinoMegaEthernetBOM.xlsx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]
